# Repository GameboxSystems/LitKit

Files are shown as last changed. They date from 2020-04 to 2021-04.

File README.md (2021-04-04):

# LitKit

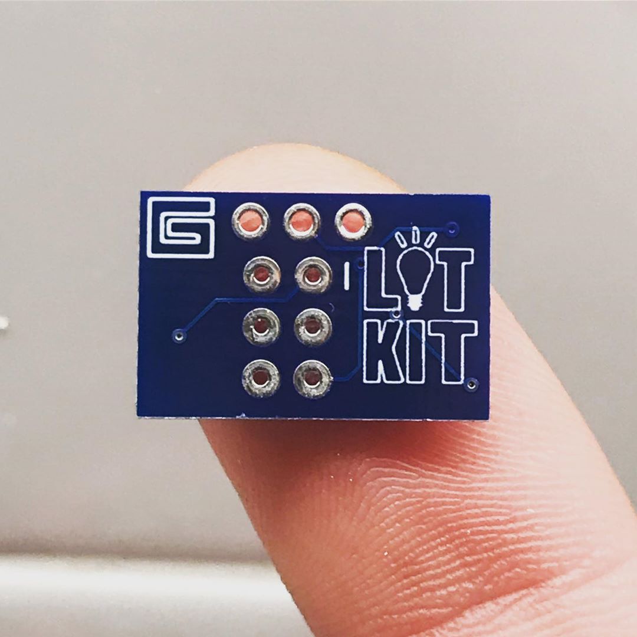
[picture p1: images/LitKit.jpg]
LitKit

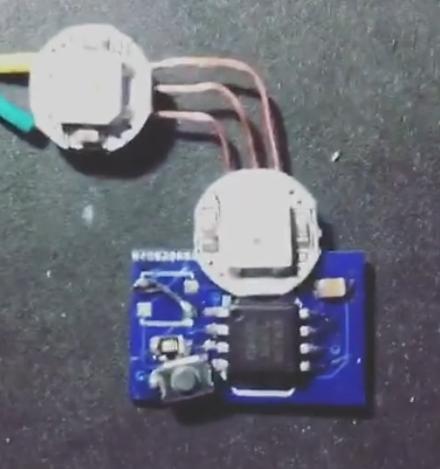
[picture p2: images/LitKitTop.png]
LitKitTop


LitKit is a tiny little Attiny85 addressable RGB LED board that features only three required parts to be funtional: Attiny85, 0.1uF cermaic 0805 cap, and a 100 ohm 0805 resistor. That's all!

Also features WS2812B 3535 on PCB, V+/GND/Data to daisy chain WS2812B LEDs to the main board, and solder pads for connecting a button.

To flash the board simply place the populated board on top a USBTinyISP boards ISP port, press down to ensure contact and flash! ISP Programming holes are measured to tension fit LitKit in place when pressed into place.

## Getting Started

### Prerequisites
Required:

* Populated LitKit Board
* Arduino IDE
* USBTinyISP Board
	* [Board tested working can be found here](https://www.ebay.com/itm/USB-Tiny-AVR-5V-ATtiny44-USBTinyISP-Programmer-For-Arduino-Bootloader/183986605082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) 

Recommended:

* 500mA + 3.3v-5v power source
* Any type of Addressable WS2812B LED array (Neopixel, LED strip, etc.)
* [Adafruit Neopixel Arduino Library](https://github.com/adafruit/Adafruit_NeoPixel)

## Software setup

* Install Arduino IDE (Tested with Arduino up to 1.8.13 from arduino.cc)
* Install TinyISP driver from https://learn.adafruit.com/usbtinyisp/download
* Open Arduino IDE
* Open File->Preferences
* Add https://raw.githubusercontent.com/damellis/attiny/ide-1.6.x-boards-manager/package_damellis_attiny_index.json to "Additional Boards Manager URLs"
* Run Tools->Board->Boards Manager
* Install "attiny" board package
* Select ATtiny25/45/85 at Tools->Board->ATtiny Microcontroller
* Select ATtiny85 at Tools->Board->Processor
* Select Internal 16 MHz at Tools->Clock
* Select USBtinyISP at Tools->Programmer

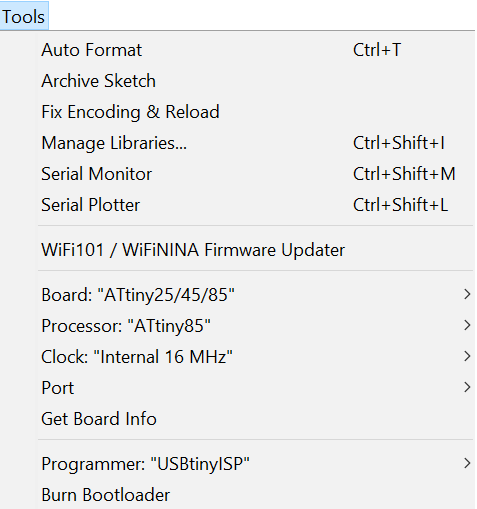
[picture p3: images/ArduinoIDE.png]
ArduinoIDE


## Examples

* Example1 - Single WS2812B demo
* Example2 - WS6812B array demo
* Example3 - Single SK6812 demo

### Run as multi file arduino sketch

* Copy src/LitKit.c and src/LitKit.h to selected example folder
* Rename LitKit.c to LitKit.ino
* Open exampleX.ino in Arduino IDE

### Flashing LitKit with USBTinyISP

*COMING SOON*

### Daisy Chaining Litkit -> LED Array

*COMING SOON*

## Currently Known Issues

N/A

## Built With

* Eagle

## Versions

v1.0 - Initial release

## Contributing

Please feel free to issue a PR or edit code freely. Would love to have people contribute ideas!

## Authors

* **Postman** - *Engineer at Gamebox Systems*
* **Knk**

## License

This project is licensed under the GPL-3.0 license, see attached license for info.

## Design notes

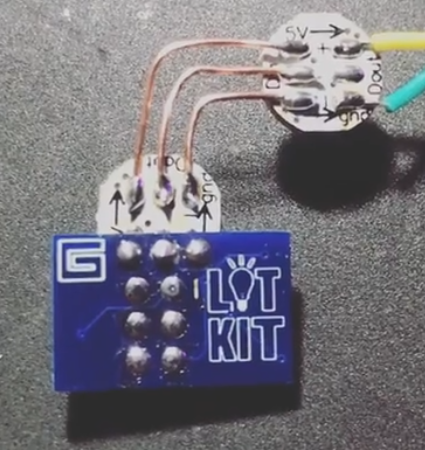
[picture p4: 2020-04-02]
images/LitKitBot.png

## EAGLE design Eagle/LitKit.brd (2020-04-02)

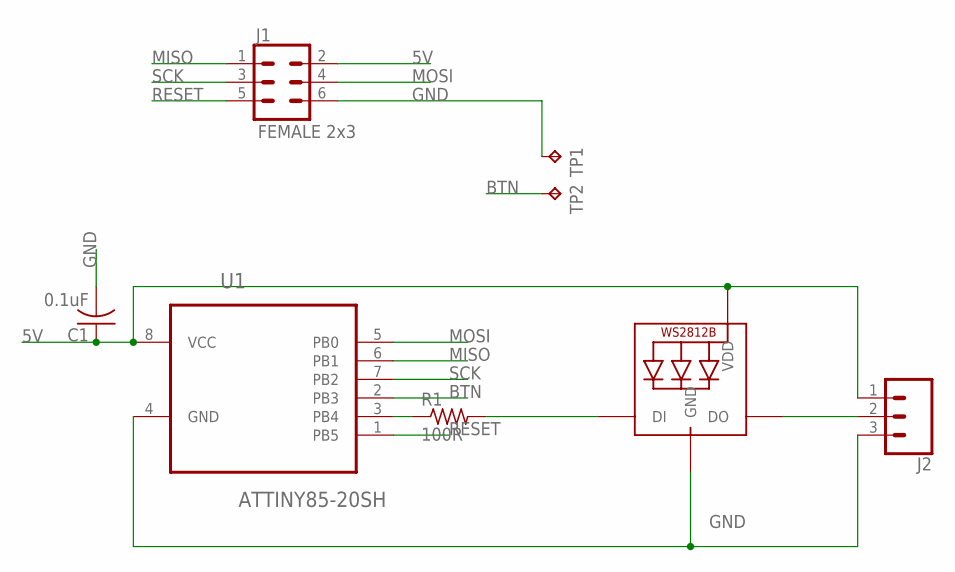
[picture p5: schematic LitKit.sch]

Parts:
C1: 0.1uF; C0805
J1: FEMALE 2x3; 2X3
J2: CONN_031X03_NO_SILK; 1X03_NO_SILK
LED1: WS2812B3535; LED3535
R1: 100R; R0805
TP1, TP2: TPB1,27; B1,27
U1: ATTINY85-20SH; SOIC127P798X216-8N

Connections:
5V: C1.1, J1.2, J2.1, LED1.2 (VDD), U1.8 (VCC)
BTN: TP2.TP, U1.2 (PB3)
GND: C1.2, J1.6, J2.3, LED1.4 (GND), TP1.TP, U1.4 (GND)
MISO: J1.1, U1.6 (PB1)
MOSI: J1.4, U1.5 (PB0)
unnamed: J2.2, LED1.3 (DO)
unnamed: R1.1, U1.3 (PB4)
unnamed: LED1.1 (DI), R1.2
RESET: J1.5, U1.1 (PB5)
SCK: J1.3, U1.7 (PB2)

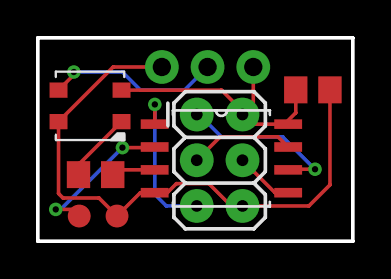
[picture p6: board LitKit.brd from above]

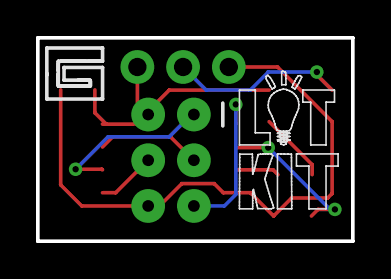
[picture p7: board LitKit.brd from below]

Board: 2 copper layers, 17.5 x 11.3 mm, 10 parts (2 on the bottom side), 10 nets.

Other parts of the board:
U$1: LITKIT
U$2: LKGB

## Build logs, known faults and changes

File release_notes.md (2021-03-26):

LitKit 1.0.0
=============

* Initial release

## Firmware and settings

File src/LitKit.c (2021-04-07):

/*H***************************************************************************
 * FILENAME :        LitKit.c
 *
 * DESCRIPTION :
 *       Basic ATtiny functions to work WS2812B LED
 *
 * PUBLIC FUNCTIONS :
 *       void ws2812b_write(uint8_t pin, uint8_t r, uint8_t g, uint8_t b)
 *
 * NOTES :
 *       Functions assume that you work with PORTB (The only possible 
 *       for ATtiny85)
 *
 * @author: Oleksandr Kiyenko
 * If you find this code useful you know what to do
 * bc1q8pflngx8qhaxtjvyhevdft4r6jvztrcm70fxz9
 *
 * @version: 1.2
 *
 * CHANGES :
 *
 * VERSION DATE        WHO     DETAIL
 * 1.0     2021.03.26  OK      Initial relase
 * 1.1     2021.03.27  OK      Multiple LEDs control
 * 1.2     2021.04.04  OK      SK6812 support
***************************************************************************H*/
#include "LitKit.h"

/**
 * @author: Oleksandr Kiyenko
 * @version: 1.0
 * Write data to a single WS2812B 
 * 
 * @param pin - Pin number from PORTB 
 * @param r   - Red intensity 0-255
 * @param g   - Green intensity 0-255
 * @param b   - Blue intensity 0-255
 * @return none
 */
void ws2812b_write(uint8_t pin, uint8_t r, uint8_t g, uint8_t b){
	uint8_t grb[3];
	grb[0] = g;
	grb[1] = r;
	grb[2] = b;
	ws2812b_stream(pin, grb, 3);
}

/**
 * @author: Oleksandr Kiyenko o.kiyenko@gmail.com
 * @version: 1.0
 * Write stream to a WS2812B 
 * 
 * @param pin - Pin number from PORTB 
 * @param grb - Array of colors in GRB format
 * @param b   - Bytes to send 0-255
 * @return none
 */
void ws2812b_stream(uint8_t pin, uint8_t* grb, uint8_t n){
  uint8_t l, h;
  uint16_t j;

  l = PORTB;                  // Port B value for "Low"
  h = l | (1 << pin);         // Port B value for "High"

  asm volatile(
    // Assembler instructions
    // 0 /400ns\850ns /6 \14
    // 1 /800ns\450ns /13\7
    // 62.5ns/cycle
	"ld r16,X+\n"			  // Load byte & inc pointer (2 ?)
    "bst r16,7\n"        	  // Load T-bit from B[7]
    "cli\n"                   // Disable interrupts
  "B7%=:\n"                   // Start of B[7]
    "out %[port], %[high]\n"  // Drive pin high
    "brtc B7_0%=\n"           // Jump if T=0
	"ld r17,X+\n"			  // Load next byte & inc pointer (2 ?)
    "dec %[cnt]\n"            // Decrement counter (1 cycle)
	"nop\n"       			  // Wait
    "bst r16,6\n"             // Load T-bit from next bit
    "out %[port], %[low]\n"   // Drive pin low
    "rjmp B6%=\n"             // Jump to next bit
  "B7_0%=:\n"                 // T=0
    "out %[port], %[low]\n"   // Drive pin low
	"ld r17,X+\n"			  // Load next byte & inc pointer (2 ?)
    "dec %[cnt]\n"            // Decrement counter (1 cycle)
	"nop\n nop\n"             // Wait
    "bst r16,6\n"             // Load T-bit from next bit
  "B6%=:\n"                   // Start of bit
    "out %[port], %[high]\n"  // Drive pin high
    "brtc B6_0%=\n"           // Jump if T=0
    "nop\n nop\n nop\n nop\n" // Wait
    "bst r16,5\n"             // Load T-bit from next bit
    "out %[port], %[low]\n"   // Drive pin low
    "rjmp B5%=\n"             // Jump to next bit
  "B6_0%=:\n"                 // T=0
    "out %[port], %[low]\n"   // Drive pin low
    "nop\n nop\n nop\n nop\n nop\n"  // Wait
    "bst r16,5\n"             // Load T-bit from next bit
  "B5%=:\n"                   // Start of bit
    "out %[port], %[high]\n"  // Drive pin high
    "brtc B5_0%=\n"           // Jump if T=0
    "nop\n nop\n nop\n nop\n" // Wait
    "bst r16,4\n"             // Load T-bit from next bit
    "out %[port], %[low]\n"   // Drive pin low
    "rjmp B4%=\n"             // Jump to next bit
  "B5_0%=:\n"                 // T=0
    "out %[port], %[low]\n"   // Drive pin low
    "nop\n nop\n nop\n nop\n nop\n"  // Wait
    "bst r16,4\n"             // Load T-bit from next bit
  "B4%=:\n"                   // Start of bit
    "out %[port], %[high]\n"  // Drive pin high
    "brtc B4_0%=\n"           // Jump if T=0
    "nop\n nop\n nop\n nop\n" // Wait
    "bst r16,3\n"             // Load T-bit from next bit
    "out %[port], %[low]\n"   // Drive pin low
    "rjmp B3%=\n"             // Jump to next bit
  "B4_0%=:\n"                 // T=0
    "out %[port], %[low]\n"   // Drive pin low
    "nop\n nop\n nop\n nop\n nop\n"  // Wait
    "bst r16,3\n"             // Load T-bit from next bit
  "B3%=:\n"                   // Start of bit
    "out %[port], %[high]\n"  // Drive pin high
    "brtc B3_0%=\n"           // Jump if T=0
    "nop\n nop\n nop\n nop\n" // Wait
    "bst r16,2\n"             // Load T-bit from next bit
    "out %[port], %[low]\n"   // Drive pin low
    "rjmp B2%=\n"             // Jump to next bit
  "B3_0%=:\n"                 // T=0
    "out %[port], %[low]\n"   // Drive pin low
    "nop\n nop\n nop\n nop\n nop\n"  // Wait
    "bst r16,2\n"             // Load T-bit from next bit
  "B2%=:\n"                   // Start of bit
    "out %[port], %[high]\n"  // Drive pin high
    "brtc B2_0%=\n"           // Jump if T=0
    "nop\n nop\n nop\n nop\n" // Wait
    "bst r16,1\n"             // Load T-bit from next bit
    "out %[port], %[low]\n"   // Drive pin low
    "rjmp B1%=\n"             // Jump to next bit
  "B2_0%=:\n"                 // T=0
    "out %[port], %[low]\n"   // Drive pin low
    "nop\n nop\n nop\n nop\n nop\n"  // Wait
    "bst r16,1\n"             // Load T-bit from next bit
  "B1%=:\n"                   // Start of bit
    "out %[port], %[high]\n"  // Drive pin high
    "brtc B1_0%=\n"           // Jump if T=0
	"nop\n nop\n nop\n"       // Wait
    "bst r16,0\n"             // Load T-bit from next bit
	"mov r16,r17\n"           // Reload data for next cycle
    "out %[port], %[low]\n"   // Drive pin low
    "rjmp B0%=\n"             // Jump to next bit
  "B1_0%=:\n"                 // T=0
    "out %[port], %[low]\n"   // Drive pin low
	"nop\n nop\n nop\n nop\n" // Wait
    "bst r16,0\n"             // Load T-bit from next bit
	"mov r16,r17\n"           // Reload data for next cycle
  "B0%=:\n"                   // Start of bit
    "out %[port], %[high]\n"  // Drive pin high
    "brtc B0_0%=\n"           // Jump if T=0
  "B0_1%=:\n"                 // T=1
    "bst r17,7\n"             // Load T-bit fot next cycle (1 cycle)
    "cpi %[cnt],0\n"          // Last transfer ?
    "brne NotLast1%=\n"       // Jump to start (1/2 cycle)
    "nop\n nop\n"             // Wait
    "out %[port], %[low]\n"   // Drive pin low
    "rjmp END%=\n"            // Jump to next bit
  "NotLast1%=:\n"             // Not Last cycle
    "nop\n"                   // Wait
    "out %[port], %[low]\n"   // Drive pin low
    "rjmp B7%=\n"             // Jump to start
  "B0_0%=:\n"                 // T=0
    "out %[port], %[low]\n"   // Drive pin low
    "bst r17,7\n"             // Load T-bit fot next cycle (1 cycle)
    "cpi %[cnt],0\n"          // Last transfer ?
    "brne NotLast0%=\n"       // Jump to start (1/2 cycle)
    "nop\n"                   // Wait
    "rjmp END%=\n"            // Jump to end
  "NotLast0%=:\n"             // Not Last cycle
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

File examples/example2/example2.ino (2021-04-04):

/*H***************************************************************************
 * FILENAME :        example2.c
 *
 * DESCRIPTION :
 *       Shows a simple usecase for LitKit library
 *       Example of WS2812B LEDs array function
 *
 * NOTES :
 *       Example for a LitKit board and Arduino IDE
 *
 * @author: Oleksandr Kiyenko
 * If you find this code useful you know what to do
 * bc1q8pflngx8qhaxtjvyhevdft4r6jvztrcm70fxz9
 *
 * @version: 1.0
 *
 * CHANGES :
 *
 * VERSION DATE        WHO     DETAIL
 * 1.0     2021.04.02  OK      Initial relase
 *
***************************************************************************H*/
#include "LitKit.h"

void setup() {
  // put your setup code here, to run once:
  // Configure PB4 as output
  DDRB |= (1 << PB4);        //replaces pinMode(PB4, OUTPUT);
}

void loop() {
  // Array for 17 LEDs (GRB format)
  uint8_t grb[51] = {100,0,0, 
     0,0,0, 20,20,20, 0,0,0, 0,50,50, 
     0,0,0, 0,0,0, 0,0,0, 20,20,20,
     20,20,20, 0,0,0, 0,0,0, 0,0,0, 
     0,0,100, 0,0,0, 20,20,20, 0,0,0};

  	ws2812b_stream(PB4, grb, 51);
  	delay(500);
}

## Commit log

2021-03-26 ATtiny85 code and Arduino configuration guide
2021-03-29 Multiple LEDs Control
2021-04-02 Load LEDs from array

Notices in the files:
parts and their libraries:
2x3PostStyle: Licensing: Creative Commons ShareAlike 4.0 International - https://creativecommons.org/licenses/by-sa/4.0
